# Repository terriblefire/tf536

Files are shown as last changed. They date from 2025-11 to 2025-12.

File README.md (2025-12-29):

# TF536






A Motorola 68030-based hardware accelerator for Amiga 500 and CDTV computers. The TF536 provides a modern 68030 CPU upgrade with SDRAM expansion, IDE interface, and custom CPLD logic for bus arbitration and peripheral management.

**Note**: For Atari ST systems, see the ST536 derivative available from [Exxos](https://www.exxosforum.co.uk/).

## Discord

https://discord.gg/Q5zfusgnmH

## Overview

The TF536 is an open-source hardware accelerator that replaces the original 68000 CPU in Amiga 500 and CDTV systems with a faster 68030 processor. The design uses a Xilinx XC95144XL/XC95288XL CPLD to implement:

- Bus arbitration between 68030 and host system
- SDRAM controller with Amiga autoconfig support
- IDE/ATA interface (Amiga Gayle chipset emulation)
- 68000 peripheral bus timing (6800-style VPA/VMA)
- Clock generation and speed control
- Interrupt handling and bus error generation

## Features

- **68030 CPU**: Significant performance upgrade from stock 68000
- **SDRAM Expansion**: Up to 128MB of fast RAM via SDRAM controller
- **IDE Interface**: Connect IDE hard drives and CF card adapters
- **Amiga Autoconfig**: Automatic memory configuration (Zorro-II compatible)
- **Multi-Platform**: Support for Amiga 500 and CDTV
- **Boot ROM**: Custom 68k assembly boot code with color cycling demo
- **Hardware Revisions**: Evolution from Rev 1 to Rev 2 with improvements
- **Automated Manufacturing**: Complete Gerber, BOM, and CPL generation

## Supported Platforms

The TF536 firmware supports two different target platforms, selected at compile time:

- **A500**: Amiga 500 configuration
- **CDTV**: Commodore CDTV configuration (different ROM decode)

Each platform has specific CPLD defines (`A500`, `CDTV`) that customize the memory map and bus interface behavior.

## Hardware Revisions

### Revision 2 (Current)
The current repository contains the **Rev 2** design (`boards/tf536r2/`), which includes:
- 4-layer PCB design
- Improved signal integrity
- JLCPCB-compatible manufacturing outputs
- Both top and bottom component placement
- Configurable IDE interface (buffered or unbuffered)

### Revision 1
Legacy design available in `boards/tf536r1/` with earlier schematic iterations.

## IDE Interface Build Options

The TF536 supports two mutually exclusive IDE interface configurations:

- **Unbuffered (Default)**: Populate RN5-RN10 with 0Ω resistor networks
- **Buffered**: Populate IC4, IC5, IC6 with buffer ICs

⚠️ **Important**: Do not populate both options simultaneously.

See [IDE_BUILD_OPTIONS.md](IDE_BUILD_OPTIONS.md) for detailed information on choosing and assembling the appropriate configuration.

## Repository Structure

```
tf536/
├── rtl/                    # Verilog RTL source code
│   ├── main_top.v         # Top-level CPLD module (parametric)
│   ├── clocks.v           # Clock generation and CPU speed control
│   ├── sdram.v            # SDRAM controller with burst support
│   ├── sdram_init.v       # SDRAM initialization state machine
│   ├── autoconfig.v       # Amiga Zorro-II autoconfiguration
│   ├── bus.v              # Bus delay and arbitration logic
│   ├── m6800.v            # Motorola 6800 peripheral bus timing
│   ├── ata.v              # IDE/ATA interface controller
│   ├── gayle.v            # Amiga Gayle IDE chipset emulation
│   ├── interrupt.v        # Interrupt level management
│   ├── intreqr.v          # Interrupt request register patching
│   └── bootrom.v          # Boot ROM (auto-generated from assembly)
├── rom/                    # Boot ROM assembly source
│   ├── bootrom.asm        # 68k assembly boot code
│   ├── bin2vrlg           # Binary to Verilog converter (Python 3)
│   └── Makefile           # ROM build automation
├── boards/                 # Board-specific build configurations
│   ├── tf536r1/           # Revision 1 board files
│   ├── tf536r2/           # Revision 2 board files (current)
│   │   ├── tf536r2_main_top.v  # Board-specific wrapper
│   │   ├── tf536r2_main.ucf    # Pin constraints
│   │   └── Makefile            # Build targets (a500, cdtv, atarist)
│   ├── Makefile.cpld      # Common CPLD synthesis rules
│   ├── Makefile.inc       # Docker/Xilinx environment setup
│   └── boards.txt         # List of board configurations
├── testsuite/             # Verilog testbenches
│   ├── bus/               # Bus interface tests
│   ├── interrupt/         # Interrupt handling tests
│   └── Makefile.inc       # Common test environment
├── eagle/                 # Eagle CAD hardware designs
│   ├── tf536.sch          # Schematic (3 sheets)
│   ├── tf536.brd          # PCB layout (4-layer)
│   ├── extract_bom.py     # BOM extraction (JLCPCB format)
│   ├── extract_cpl.py     # Component placement list
│   ├── jlcpcb_4_layer_v9.cam  # Gerber generation CAM job
│   └── Makefile           # Automated manufacturing outputs
└── .github/workflows/     # CI/CD automation
    ├── build-firmware.yml     # CPLD firmware builds
    ├── gerbers.yml            # Gerber file generation
    ├── schematic-pdf.yml      # PDF schematic generation
    └── generate_assembly.yml  # BOM and CPL generation
```

## Building the CPLD Firmware

### Prerequisites

- **Linux**: Xilinx ISE 10.1 installed at `/opt/Xilinx/10.1/`
- **macOS/Windows**: Docker (automatically uses terriblefire78/xilinx:v1 container)
- **68k Assembly**: vasmm68k_mot assembler for boot ROM

The build system automatically handles Docker on non-Linux platforms.

### Build Boot ROM

```bash
cd rom
make
```

Generates `bootrom.v` from `bootrom.asm` with embedded version string.

### Build All Platforms

```bash
cd boards/tf536r2
make
```

This compiles CPLD firmware for both platforms using the XC95288XL CPLD:
- `tf536r2_main_top_A500_XC95288XL_PHASE_7.jed` (Amiga 500)
- `tf536r2_main_top_CDTV_XC95288XL_PHASE_7.jed` (CDTV)

### Build Specific Platform

```bash
cd boards/tf536r2
make a500      # Amiga 500
make cdtv      # Commodore CDTV
```

Output: `.jed` (JEDEC programming files) and `.svf` (Serial Vector Format)

### Build Configuration

Key Makefile variables (used internally by `boards/tf536r2/Makefile`):

```makefile
CHIPSIZE=288        # XC95288XL CPLD
CLOCK_PHASE=7       # Clock phase alignment (0-7)
TARGET=A500         # Platform target (A500, CDTV)
```

### Clean Build Artifacts

```bash
cd boards
make clean       # Remove intermediate files, keep .jed
make distclean   # Remove all generated files including .jed
```

### Create Release Package

```bash
cd boards
make zip
```

Generates: `tf536_YYYY_MM_DD_<git-hash>.zip` containing all board `.jed` files.

## Hardware Manufacturing

### Generate Gerber Files

```bash
cd eagle
make gerbers
```

Output: `tf536_<git>_<date>.zip` containing complete 4-layer PCB fabrication package for JLCPCB.

### Generate PDF Schematic

```bash
cd eagle
make pdf
```

Output: `tf536_<git>_<date>.pdf` - Multi-page PDF schematic (3 sheets)

### Generate Assembly Files

```bash
cd eagle
make assembly
```

Generates:
- `tf536_bom.csv` - Bill of Materials (JLCPCB format)
- `tf536_cpl.csv` - Component Placement List for SMT assembly

### Complete Manufacturing Output

```bash
cd eagle
make all         # Gerber files + ZIP
make bom         # Bill of Materials only
make cpl         # Component Placement List only
make clean       # Remove all generated files
```

## RTL Architecture

### Module Hierarchy

**Top-level:** `main_top.v` (parametric, instantiated by board-specific wrapper)

**Key Modules:**
- **`clocks.v`**: Clock management, CPU speed control, 7MHz/100MHz domain crossing
- **`sdram.v`**: SDRAM controller with burst read/write, refresh, autoconfig decode
- **`sdram_init.v`**: SDRAM initialization (precharge, auto-refresh, mode register)
- **`autoconfig.v`**: Amiga Zorro-II autoconfiguration protocol
- **`bus.v`**: Bus delay state machine and control
- **`m6800.v`**: Motorola 6800 peripheral bus timing (VPA/VMA/E-clock)
- **`ata.v`**: IDE/ATA interface with wait state generation
- **`gayle.v`**: Amiga Gayle chipset emulation (IDE interrupt, status)
- **`interrupt.v`**: IPL interrupt level assertion and acknowledgment
- **`intreqr.v`**: INTREQ/INTENA register patching for IDE interrupts
- **`bootrom.v`**: Boot ROM lookup table (auto-generated from assembly)

### Design Patterns

- **Dual-clock design**: CLK7M (7MHz Amiga bus) and CLK100M (system/SDRAM)
- **Bus punting**: Decides when to drive Amiga bus vs. tri-state (HIGHZ)
- **Platform-specific compilation**: `ifdef` directives for A500/CDTV
- **DSACK protocol**: Variable wait state insertion for fast RAM access
- **Cache support**: CBREQ/CBACK/CIIN signals for 68030 cache control

### Memory Map

**Amiga Configuration:**
- `$00000000-$001FFFFF`: Chip RAM (host)
- `$00200000-$009FFFFF`: Autoconfig space
- `$00A00000-$00BFFFFF`: Reserved (CIA, Custom chips)
- `$00C00000-$00DFFFFF`: Slow RAM (host)
- `$00E00000-$00E7FFFF`: Autoconfig ROM
- `$00F00000-$00F7FFFF`: Cartridge ROM (unless CDTV)
- `$00F80000-$00FFFFFF`: System ROM (Kickstart)
- `$01000000+`: Fast RAM (SDRAM, autoconfigured)

**CDTV Configuration:**
- ROM decode disabled at `$00F00000` (see `main_top.v:268-272`)

## Testing

Run Verilog testbenches:

```bash
cd testsuite/interrupt
make

cd testsuite/bus
make
```

Testbenches use Icarus Verilog (iverilog) and follow naming convention `test_*.v`.

## Programming the CPLD

The `.jed` files can be programmed using:
- JTAG programmer (Xilinx Platform Cable, etc.)
- xc3sprog with FT232H-based programmer
- Xilinx iMPACT software

## CI/CD Automation

GitHub Actions automatically builds:
- **CPLD Firmware**: On changes to `rtl/`, `boards/`, or `rom/`
- **Gerber Files**: On push to develop/main branches
- **PDF Schematics**: On push to develop/main branches
- **Assembly Files**: On changes to Eagle files or extraction scripts

All build artifacts are uploaded and available for download for 90 days. Tagged releases automatically include manufacturing outputs.

## License

This work is licensed under the Creative Commons Attribution-NoDerivatives 4.0 International License.

Copyright (c) 2016-2025 Stephen J. Leary

You are free to:
- **Share** - copy and redistribute the material in any medium or format for any purpose, even commercially

Under the following terms:
- **Attribution** - You must give appropriate credit, provide a link to the license, and indicate if changes were made
- **NoDerivatives** - If you remix, transform, or build upon the material, you may not distribute the modified material

See the [LICENSE](LICENSE) file for the complete license text, or visit:
https://creativecommons.org/licenses/by-nd/4.0/

## Community

Join the TerribleFire Discord for support, discussions, and updates: https://discord.gg/aXGkKWJQ

## Credits

- Hardware design: Stephen Leary
- CPLD development: Stephen Leary
- Open source contributions welcome!

---

**Note**: This is a complex hardware project requiring experience with:
- Eagle CAD for hardware modifications
- Verilog HDL for CPLD changes
- 68000/68030 assembly for boot ROM modifications
- Xilinx ISE 10.1 toolchain for CPLD synthesis
- PCB fabrication and SMT assembly services

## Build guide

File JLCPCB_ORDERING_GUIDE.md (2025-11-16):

# JLCPCB Ordering Guide for the **TF536** Project

This guide walks you step‑by‑step through ordering the **TF536** PCB from JLCPCB using the files provided in the GitHub repository: <https://github.com/terriblefire/tf536>

It is written for beginners and assumes **no prior PCB ordering experience**.

---

## 📁 1. Download and Extract the Release Package

1. Go to the GitHub repository: <https://github.com/terriblefire/tf536>
2. Open the **Releases** section.
3. Download the **single release ZIP file** (e.g., `tf536_v1.0.0.zip`).
4. Extract the ZIP. You will see a structure like this:

```
assembly/
    tf536_bom.csv
    tf536_cpl.csv

pcb/
    tf536_XXXX.zip   (Gerber manufacturing file)

firmware/
    *.jed files (A500 and CDTV variants)

docs/
    PDF documentation, README, LICENSE, IDE_BUILD_OPTIONS.md
```

The files needed for JLCPCB are:
- **Gerber ZIP file:** located in the `pcb/` folder
- **BOM file:** `assembly/tf536_bom.csv`
- **CPL file:** `assembly/tf536_cpl.csv`

---

## 🏭 2. Start a PCB Order on JLCPCB

1. Go to **https://jlcpcb.com**
2. Click **"Order Now"** or **"Quote Now"**.
3. Drag and drop the **Gerber ZIP file** into the upload area.

JLCPCB will automatically detect the board size and number of layers.

> **Note:** JLCPCB does *not* always detect PCB thickness. For TF536, set **1.6 mm thickness manually**.

---

## ⚙️ 3. Configure the PCB Options (Minimal Setup)

The default settings are fine unless otherwise specified by the project.

Recommended settings:

- **Quantity:** 5 or 10 (your choice)
- **PCB Color:** Any (personal preference)
- **Thickness:** 1.6 mm (set manually if not detected)
- **Surface Finish:** HASL or ENIG (ENIG gives nicer gold pads but costs more)
- **Remove Order Number:** Optional (JLCPCB may charge extra)

Everything else can remain at default unless the project documentation says otherwise.

---

## 🤖 4. Add PCB Assembly (If you want components pre‑soldered)

If this project supports assembly (check the repo):

1. Enable **"PCB Assembly"**
2. Select **Left Side / Top Side** (as required by the project)
3. Upload the following when prompted:
   - **BOM file**
   - **CPL file**

JLCPCB will parse the files and show a component placement preview.

### Review the Assembly Bill of Materials

JLCPCB will display:
- A list of recognised components
- Any unmatched parts (you may need to pick substitutes)
- Costs for assembly

> If any parts show as *"Not Found"*, check the BOM or the GitHub project's documentation for substitute part numbers.

---

## 🔍 5. Review the PCB Preview

You will see:
- The Gerber viewer (copper traces, drill holes, etc.)
- Assembly view (if assembly is enabled)

Make sure:
- The board outline looks correct
- Components appear on the correct side
- No warnings are shown

---

## 🛒 6. Add to Cart and Checkout

1. Click **"Add to Cart"**
2. Verify your order summary
3. Proceed to **Checkout**
4. Enter your shipping address
5. Choose a shipping method (DHL is fastest)
6. Pay using:
   - Credit/Debit card
   - PayPal
   - Other supported methods

---

## 📦 7. Wait for Production

Typical manufacturing times:
- **Bare PCBs:** 2–3 days
- **Assembly:** 3–7 days (depends on part availability)

Shipping time varies by region.

You can track the order progress in your JLCPCB account.

---

## 🎉 8. When the Boards Arrive

Inside the package you will find:
- Your PCBs (bare or assembled)
- Any remaining unused components (for assembly orders)
- QC sticker or summary

Inspect the board visually. If assembled, verify correct component placement.

---

## 🧩 9. Additional Notes for TF536 Users

- **IDE Interface Options:** The TF536 has two mutually exclusive build options for the IDE interface:
  - **Unbuffered (Default):** Populate RN5-RN10 with 0Ω resistor networks
  - **Buffered:** Populate IC4, IC5, IC6 with buffer ICs
  - ⚠️ **Never populate both!** See `IDE_BUILD_OPTIONS.md` in the docs folder for details.
- Check the GitHub repo for **firmware**, **build notes**, or **updates**.
- Some components may need to be hand‑soldered depending on your chosen configuration.
- Refer to the project README for configuration or installation instructions.

---

## ❓ Need Help?
If you want a version with screenshots, clearer beginner steps, or additional troubleshooting (e.g., BOM import errors), just ask and I can extend this document further.

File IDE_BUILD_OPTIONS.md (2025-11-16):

# TF536 IDE Interface Build Options

The TF536 board supports two different IDE interface configurations. You must choose ONE of these options during assembly - **do not populate both**.

## Option 1: Unbuffered IDE Interface (Default)

**Components to populate:**
- RN5, RN6, RN7, RN8, RN9, RN10 (0Ω resistor networks)

**Components to leave unpopulated:**
- IC4, IC5, IC6 (buffer ICs)

This is the simpler, lower-cost build option suitable for most applications.

## Option 2: Buffered IDE Interface

**Components to populate:**
- IC4, IC5, IC6 (buffer ICs)

**Components to leave unpopulated:**
- RN5, RN6, RN7, RN8, RN9, RN10 (resistor networks)

The buffered interface provides:
- Better signal integrity for longer IDE cables
- Improved electrical isolation between the TF536 and IDE devices
- Enhanced protection for the CPLD and host system

## Important Notes

⚠️ **WARNING**: Do not populate both the resistor networks (RN5-RN10) and the buffer ICs (IC4-IC6) simultaneously. This will cause signal conflicts and may damage the board.

## Choosing the Right Option

### Use Unbuffered (Default) if:
- Using standard length IDE cables (< 18 inches / 45 cm)
- Cost optimization is important
- Board space or component availability is limited

### Use Buffered if:
- Using longer IDE cables
- Requiring maximum signal integrity
- Operating in electrically noisy environments
- Using multiple IDE devices or CF card adapters with high-speed operation

## Assembly Tips

1. If assembling for the first time, start with the unbuffered option (resistor networks)
2. The resistor networks are typically cheaper and easier to source
3. For JLCPCB assembly, specify which option you want in the assembly notes
4. When hand-soldering, double-check that you're only populating one set of components

## BOM Modifications

When ordering from JLCPCB or generating your BOM:

**For Unbuffered build:**
- Include: RN5, RN6, RN7, RN8, RN9, RN10
- Exclude: IC4, IC5, IC6

**For Buffered build:**
- Include: IC4, IC5, IC6
- Exclude: RN5, RN6, RN7, RN8, RN9, RN10

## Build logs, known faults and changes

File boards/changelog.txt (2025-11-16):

RC3 2021/03/31 Fixed the IDE lockup issue and added unit tests so this doesnt regress.

Serial number changed to 536
Product code 4 

RC2 2020/08/02

Advanced the CIA read timing code. Noticed it was managing to read after the data had disappeared from CIA A in DiagROM.

Fixes: A2000 compatibility.

RC1 2020/08/01

Changed the timing for the 030.
Fixes: Turrican II and Damocles.

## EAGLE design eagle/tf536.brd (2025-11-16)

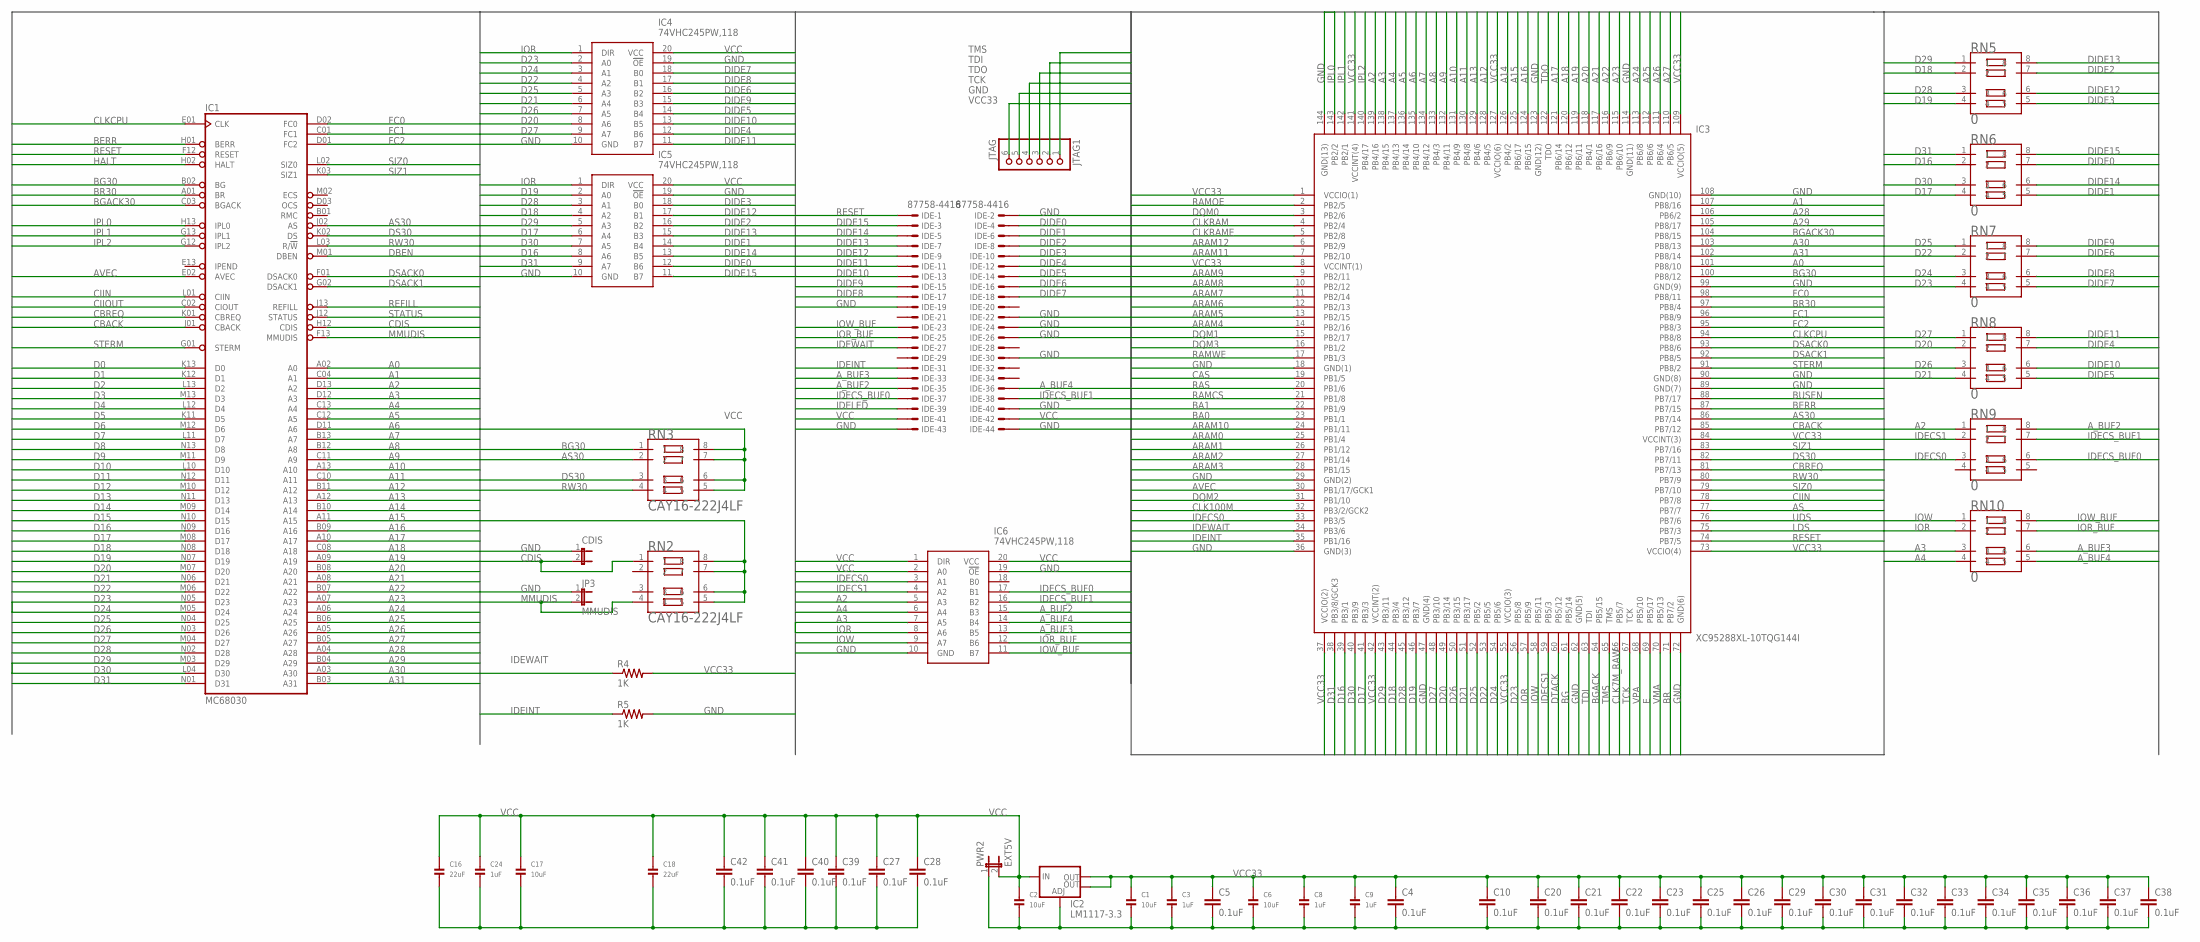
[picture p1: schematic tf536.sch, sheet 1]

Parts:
C1, C2, C6, C17: 10uF; 1206
C3, C8, C9, C24: 1uF; 1206
C4, C5, C10, C20, C21, C22, C23, C25, C26, C27, C28, C29, C30, C31, C32, C33, C34, C35, C36, C37, C38, C39, C40, C41, C42: 0.1uF; 0603-CAP
C16, C18: 22uF; 1206
IC1: MC68030; MPGA128
IC2: LM1117-3.3; SOT223
IC3: XC95288XL-10TQG144I; SAMACSYS_PARTS_QFP50P2200X2200X160-144N
IC4, IC5, IC6: 74VHC245PW,118; SOP65P640X110-20N
IDE: 87758-4416
JP3: MMUDIS; 1X02
JP5: CDIS; 1X02
JTAG1: JTAG; 1X06_ROUND
PWR2: EXT5V; 1X02
R4, R5: 1K; 0603
RN2, RN3: CAY16-222J4LF; RESCAXE80P320X160-8N
RN5, RN6, RN7, RN8, RN9, RN10: 0; RESCAXE80P320X160-8N

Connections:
A0: IC1.A02 (A0), IC3.101 (PB8/10)
A1: IC1.C04 (A1), IC3.107 (PB8/16); also elsewhere on the board
A2: IC1.D13 (A2), IC3.139 (PB4/16), IC6.5 (A3), RN9.1; also elsewhere on the board
A3: IC1.D12 (A3), IC3.138 (PB4/15), IC6.7 (A5), RN10.3; also elsewhere on the board
A4: IC1.C13 (A4), IC3.137 (PB4/13), IC6.6 (A4), RN10.4; also elsewhere on the board
A5: IC1.C12 (A5), IC3.136 (PB4/14); also elsewhere on the board
A6: IC1.D11 (A6), IC3.135 (PB4/10); also elsewhere on the board
A7: IC1.B13 (A7), IC3.134 (PB4/12); also elsewhere on the board
A8: IC1.B12 (A8), IC3.133 (PB4/3); also elsewhere on the board
A9: IC1.C11 (A9), IC3.132 (PB4/11); also elsewhere on the board
A10: IC1.A13 (A10), IC3.131 (PB4/9); also elsewhere on the board
A11: IC1.C10 (A11), IC3.130 (PB4/8); also elsewhere on the board
A12: IC1.B11 (A12), IC3.128 (PB4/5); also elsewhere on the board
A13: IC1.A12 (A13), IC3.129 (PB4/6); also elsewhere on the board
A14: IC1.B10 (A14), IC3.126 (PB4/2); also elsewhere on the board
A15: IC1.A11 (A15), IC3.125 (PB6/17); also elsewhere on the board
A16: IC1.B09 (A16), IC3.124 (PB6/15); also elsewhere on the board
A17: IC1.A10 (A17), IC3.121 (PB6/14); also elsewhere on the board
A18: IC1.C08 (A18), IC3.120 (PB6/12); also elsewhere on the board
A19: IC1.A09 (A19), IC3.119 (PB6/11); also elsewhere on the board
A20: IC1.B08 (A20), IC3.118 (PB4/1); also elsewhere on the board
A21: IC1.A08 (A21), IC3.117 (PB6/16); also elsewhere on the board
A22: IC1.B07 (A22), IC3.116 (PB6/9); also elsewhere on the board
A23: IC1.A07 (A23), IC3.115 (PB6/10); also elsewhere on the board
A24: IC1.A06 (A24), IC3.113 (PB6/8); also elsewhere on the board
A25: IC1.B06 (A25), IC3.112 (PB6/6); also elsewhere on the board
A26: IC1.A05 (A26), IC3.111 (PB6/4); also elsewhere on the board
A27: IC1.B05 (A27), IC3.110 (PB6/5); also elsewhere on the board
A28: IC1.A04 (A28), IC3.106 (PB6/2); also elsewhere on the board
A29: IC1.B04 (A29), IC3.105 (PB8/17); also elsewhere on the board
A30: IC1.A03 (A30), IC3.103 (PB8/13); also elsewhere on the board
A31: IC1.B03 (A31), IC3.102 (PB8/14); also elsewhere on the board
ARAM0: IC3.25 (PB1/4); also elsewhere on the board
ARAM1: IC3.26 (PB1/12); also elsewhere on the board
ARAM2: IC3.27 (PB1/14); also elsewhere on the board
ARAM3: IC3.28 (PB1/15); also elsewhere on the board
ARAM4: IC3.14 (PB2/16); also elsewhere on the board
ARAM5: IC3.13 (PB2/15); also elsewhere on the board
ARAM6: IC3.12 (PB2/13); also elsewhere on the board
ARAM7: IC3.11 (PB2/14); also elsewhere on the board
ARAM8: IC3.10 (PB2/12); also elsewhere on the board
ARAM9: IC3.9 (PB2/11); also elsewhere on the board
ARAM10: IC3.24 (PB1/11); also elsewhere on the board
ARAM11: IC3.7 (PB2/10); also elsewhere on the board
ARAM12: IC3.6 (PB2/9); also elsewhere on the board
AS: IC3.77 (PB7/7); also elsewhere on the board
AS30: IC1.J02 (AS), IC3.86 (PB7/14), RN3.2
AVEC: IC1.E02 (AVEC), IC3.30 (PB1/17/GCK1)
A_BUF2: IC6.15 (B3), IDE.35, RN9.8
A_BUF3: IC6.13 (B5), IDE.33, RN10.6
A_BUF4: IC6.14 (B4), IDE.36, RN10.5
BA0: IC3.23 (PB1/1); also elsewhere on the board
BA1: IC3.22 (PB1/9); also elsewhere on the board
BERR: IC1.H01 (BERR), IC3.87 (PB7/15); also elsewhere on the board
BG: IC3.61 (PB5/14); also elsewhere on the board
BG30: IC1.B02 (BG), IC3.100 (PB8/12), RN3.1
BGACK: IC3.64 (PB5/15); also elsewhere on the board
BGACK30: IC1.C03 (BGACK), IC3.104 (PB8/15)
BR: IC3.71 (PB7/2); also elsewhere on the board
BR30: IC1.A01 (BR), IC3.97 (PB8/4)
BUSEN: IC3.88 (PB7/17); also elsewhere on the board
CAS: IC3.19 (PB1/5); also elsewhere on the board
CBACK: IC1.J01 (CBACK), IC3.85 (PB7/12)
CBREQ: IC1.K01 (CBREQ), IC3.81 (PB7/13)
CDIS: IC1.H12 (CDIS), JP5.2, RN2.1
CIIN: IC1.L01 (CIIN), IC3.78 (PB7/8)
CIIOUT: IC1.C02 (CIOUT)
CLK7M_RAW: IC3.66 (PB5/7); also elsewhere on the board
CLK100M: IC3.32 (PB3/2/GCK2); also elsewhere on the board
CLKCPU: IC1.E01 (CLK), IC3.94 (PB8/8)
CLKRAM: IC3.4 (PB2/4); also elsewhere on the board
CLKRAME: IC3.5 (PB2/8); also elsewhere on the board
D0: IC1.K13 (D0); also elsewhere on the board
D1: IC1.K12 (D1); also elsewhere on the board
D2: IC1.L13 (D2); also elsewhere on the board
D3: IC1.M13 (D3); also elsewhere on the board
D4: IC1.L12 (D4); also elsewhere on the board
D5: IC1.K11 (D5); also elsewhere on the board
D6: IC1.M12 (D6); also elsewhere on the board
D7: IC1.L11 (D7); also elsewhere on the board
D8: IC1.N13 (D8); also elsewhere on the board
D9: IC1.M11 (D9); also elsewhere on the board
D10: IC1.L10 (D10); also elsewhere on the board
D11: IC1.N12 (D11); also elsewhere on the board
D12: IC1.M10 (D12); also elsewhere on the board
D13: IC1.N11 (D13); also elsewhere on the board
D14: IC1.M09 (D14); also elsewhere on the board
D15: IC1.N10 (D15); also elsewhere on the board
D16: IC1.N09 (D16), IC3.39 (PB3/1), IC5.8 (A6), RN6.2; also elsewhere on the board
D17: IC1.M08 (D17), IC3.41 (PB3/3), IC5.6 (A4), RN6.4; also elsewhere on the board
D18: IC1.N08 (D18), IC3.44 (PB3/4), IC5.4 (A2), RN5.2; also elsewhere on the board
D19: IC1.N07 (D19), IC3.46 (PB3/7), IC5.2 (A0), RN5.4; also elsewhere on the board
D20: IC1.M07 (D20), IC3.49 (PB3/14), IC4.8 (A6), RN8.2; also elsewhere on the board
D21: IC1.N06 (D21), IC3.51 (PB3/17), IC4.6 (A4), RN8.4; also elsewhere on the board
D22: IC1.M06 (D22), IC3.53 (PB5/5), IC4.4 (A2), RN7.2; also elsewhere on the board
D23: IC1.N05 (D23), IC3.56 (PB5/8), IC4.2 (A0), RN7.4; also elsewhere on the board
D24: IC1.M05 (D24), IC3.54 (PB5/6), IC4.3 (A1), RN7.3; also elsewhere on the board
D25: IC1.N04 (D25), IC3.52 (PB5/2), IC4.5 (A3), RN7.1; also elsewhere on the board
D26: IC1.N03 (D26), IC3.50 (PB3/15), IC4.7 (A5), RN8.3; also elsewhere on the board
D27: IC1.M04 (D27), IC3.48 (PB3/10), IC4.9 (A7), RN8.1; also elsewhere on the board
D28: IC1.N02 (D28), IC3.45 (PB3/12), IC5.3 (A1), RN5.3; also elsewhere on the board
D29: IC1.M03 (D29), IC3.43 (PB3/11), IC5.5 (A3), RN5.1; also elsewhere on the board
D30: IC1.L04 (D30), IC3.40 (PB3/9), IC5.7 (A5), RN6.3; also elsewhere on the board
D31: IC1.N01 (D31), IC3.38 (PB3/8/GCK3), IC5.9 (A7), RN6.1; also elsewhere on the board
DBEN: IC1.M01 (DBEN)
DIDE0: IC5.12 (B6), IDE.4, RN6.7
DIDE1: IC5.14 (B4), IDE.6, RN6.5
DIDE2: IC5.16 (B2), IDE.8, RN5.7
DIDE3: IC5.18 (B0), IDE.10, RN5.5
DIDE4: IC4.12 (B6), IDE.12, RN8.7
DIDE5: IC4.14 (B4), IDE.14, RN8.5
DIDE6: IC4.16 (B2), IDE.16, RN7.7
DIDE7: IC4.18 (B0), IDE.18, RN7.5
DIDE8: IC4.17 (B1), IDE.17, RN7.6
DIDE9: IC4.15 (B3), IDE.15, RN7.8
DIDE10: IC4.13 (B5), IDE.13, RN8.6
DIDE11: IC4.11 (B7), IDE.11, RN8.8
DIDE12: IC5.17 (B1), IDE.9, RN5.6
DIDE13: IC5.15 (B3), IDE.7, RN5.8
DIDE14: IC5.13 (B5), IDE.5, RN6.6
DIDE15: IC5.11 (B7), IDE.3, RN6.8
DQM0: IC3.3 (PB2/6); also elsewhere on the board
DQM1: IC3.15 (PB2/17); also elsewhere on the board
DQM2: IC3.31 (PB1/10); also elsewhere on the board
DQM3: IC3.16 (PB1/2); also elsewhere on the board
DS30: IC1.K02 (DS), IC3.82 (PB7/11), RN3.3
DSACK0: IC1.F01 (DSACK0), IC3.93 (PB8/6)
DSACK1: IC1.G02 (DSACK1), IC3.92 (PB8/5)
DTACK: IC3.60 (PB5/12); also elsewhere on the board
E: IC3.69 (PB5/17); also elsewhere on the board
FC0: IC1.D02 (FC0), IC3.98 (PB8/11); also elsewhere on the board
FC1: IC1.C01 (FC1), IC3.96 (PB8/9); also elsewhere on the board
FC2: IC1.D01 (FC2), IC3.95 (PB8/3); also elsewhere on the board
GND: C1.2, C2.2, C3.2, C4.2, C5.2, C6.2, C8.2, C9.2, C10.2, C16.2, C17.2, C18.2, C20.2, C21.2, C22.2, C23.2, C24.2, C25.2, C26.2, C27.2, C28.2, C29.2, C30.2, C31.2, C32.2, C33.2, C34.2, C35.2, C36.2, C37.2, C38.2, C39.2, C40.2, C41.2, C42.2, IC1.C05 (GND), IC1.C07 (GND), IC1.C09 (GND), IC1.E03 (GND), IC1.E11 (GND), IC1.F03 (GND), IC1.G03 (GND), IC1.G11 (GND), IC1.J03 (GND), IC1.J11 (GND), IC1.L05 (GND), IC1.L07 (GND), IC1.L08 (GND), IC1.L09 (GND), IC2.1 (ADJ), IC3.18 (GND(1)), IC3.29 (GND(2)), IC3.36 (GND(3)), IC3.47 (GND(4)), IC3.62 (GND(5)), IC3.72 (GND(6)), IC3.89 (GND(7)), IC3.90 (GND(8)), IC3.99 (GND(9)), IC3.108 (GND(10)), IC3.114 (GND(11)), IC3.123 (GND(12)), IC3.144 (GND(13)), IC4.10 (GND), IC4.19 (!OE), IC5.10 (GND), IC5.19 (!OE), IC6.10 (GND), IC6.19 (!OE), IDE.2, IDE.19, IDE.22, IDE.24, IDE.26, IDE.30, IDE.40, IDE.43, IDE.44, JP3.1, JP5.1, JTAG1.5, PWR2.1, R5.2; also elsewhere on the board
HALT: IC1.H02 (HALT); also elsewhere on the board
IDECS0: IC3.33 (PB3/5), IC6.3 (A1), RN9.3
IDECS1: IC3.59 (PB5/3), IC6.4 (A2), RN9.2
IDECS_BUF0: IC6.17 (B1), IDE.37, RN9.6
IDECS_BUF1: IC6.16 (B2), IDE.38, RN9.7
IDEINT: IC3.35 (PB1/16), IDE.31, R5.1
IDELED: IDE.39
IDEWAIT: IC3.34 (PB3/6), IDE.27, R4.1
IOR: IC3.57 (PB5/9), IC4.1 (DIR), IC5.1 (DIR), IC6.8 (A6), RN10.2
IOR_BUF: IC6.12 (B6), IDE.25, RN10.7
IOW: IC3.58 (PB5/11), IC6.9 (A7), RN10.1
IOW_BUF: IC6.11 (B7), IDE.23, RN10.8
IPL0: IC1.H13 (IPL0), IC3.143 (PB2/2); also elsewhere on the board
IPL1: IC1.G13 (IPL1), IC3.142 (PB2/1); also elsewhere on the board
IPL2: IC1.G12 (IPL2), IC3.140 (PB4/17); also elsewhere on the board
LDS: IC3.75 (PB7/3); also elsewhere on the board
MMUDIS: IC1.F13 (MMUDIS), JP3.2, RN2.4
RAMCS: IC3.21 (PB1/8); also elsewhere on the board
RAMOE: IC3.2 (PB2/5); also elsewhere on the board
RAMWE: IC3.17 (PB1/3); also elsewhere on the board
RAS: IC3.20 (PB1/6); also elsewhere on the board
REFILL: IC1.J13 (REFILL)
RESET: IC1.F12 (RESET), IC3.74 (PB7/5), IDE.1; also elsewhere on the board
RW30: IC1.L03 (R/!W), IC3.80 (PB7/9), RN3.4; also elsewhere on the board
SIZ0: IC1.L02 (SIZ0), IC3.79 (PB7/10)
SIZ1: IC1.K03 (SIZ1), IC3.83 (PB7/16)
STATUS: IC1.J12 (STATUS)
STERM: IC1.G01 (STERM), IC3.91 (PB8/2)
TCK: IC3.67 (TCK), JTAG1.4
TDI: IC3.63 (TDI), JTAG1.2
TDO: IC3.122 (TDO), JTAG1.3
TMS: IC3.65 (TMS), JTAG1.1
UDS: IC3.76 (PB7/6); also elsewhere on the board
VCC: C2.1, C16.1, C17.1, C18.1, C24.1, C27.1, C28.1, C39.1, C40.1, C41.1, C42.1, IC1.C06 (VCC), IC1.D04 (VCC), IC1.D10 (VCC), IC1.F02 (VCC), IC1.F11 (VCC), IC1.H03 (VCC), IC1.H11 (VCC), IC1.K04 (VCC), IC1.K10 (VCC), IC1.L06 (VCC), IC2.3 (IN), IC4.20 (VCC), IC5.20 (VCC), IC6.1 (DIR), IC6.2 (A0), IC6.20 (VCC), IDE.41, IDE.42, PWR2.2, RN3.5, RN3.6, RN3.7, RN3.8; also elsewhere on the board
VCC33: C1.1, C3.1, C4.1, C5.1, C6.1, C8.1, C9.1, C10.1, C20.1, C21.1, C22.1, C23.1, C25.1, C26.1, C29.1, C30.1, C31.1, C32.1, C33.1, C34.1, C35.1, C36.1, C37.1, C38.1, IC2.2 (OUT), IC2.4 (OUT), IC3.1 (VCCIO(1)), IC3.8 (VCCINT(1)), IC3.37 (VCCIO(2)), IC3.42 (VCCINT(2)), IC3.55 (VCCIO(3)), IC3.73 (VCCIO(4)), IC3.84 (VCCINT(3)), IC3.109 (VCCIO(5)), IC3.127 (VCCIO(6)), IC3.141 (VCCINT(4)), JTAG1.6, R4.2, RN2.5, RN2.6, RN2.7, RN2.8; also elsewhere on the board
VMA: IC3.70 (PB5/13); also elsewhere on the board
VPA: IC3.68 (PB5/10); also elsewhere on the board

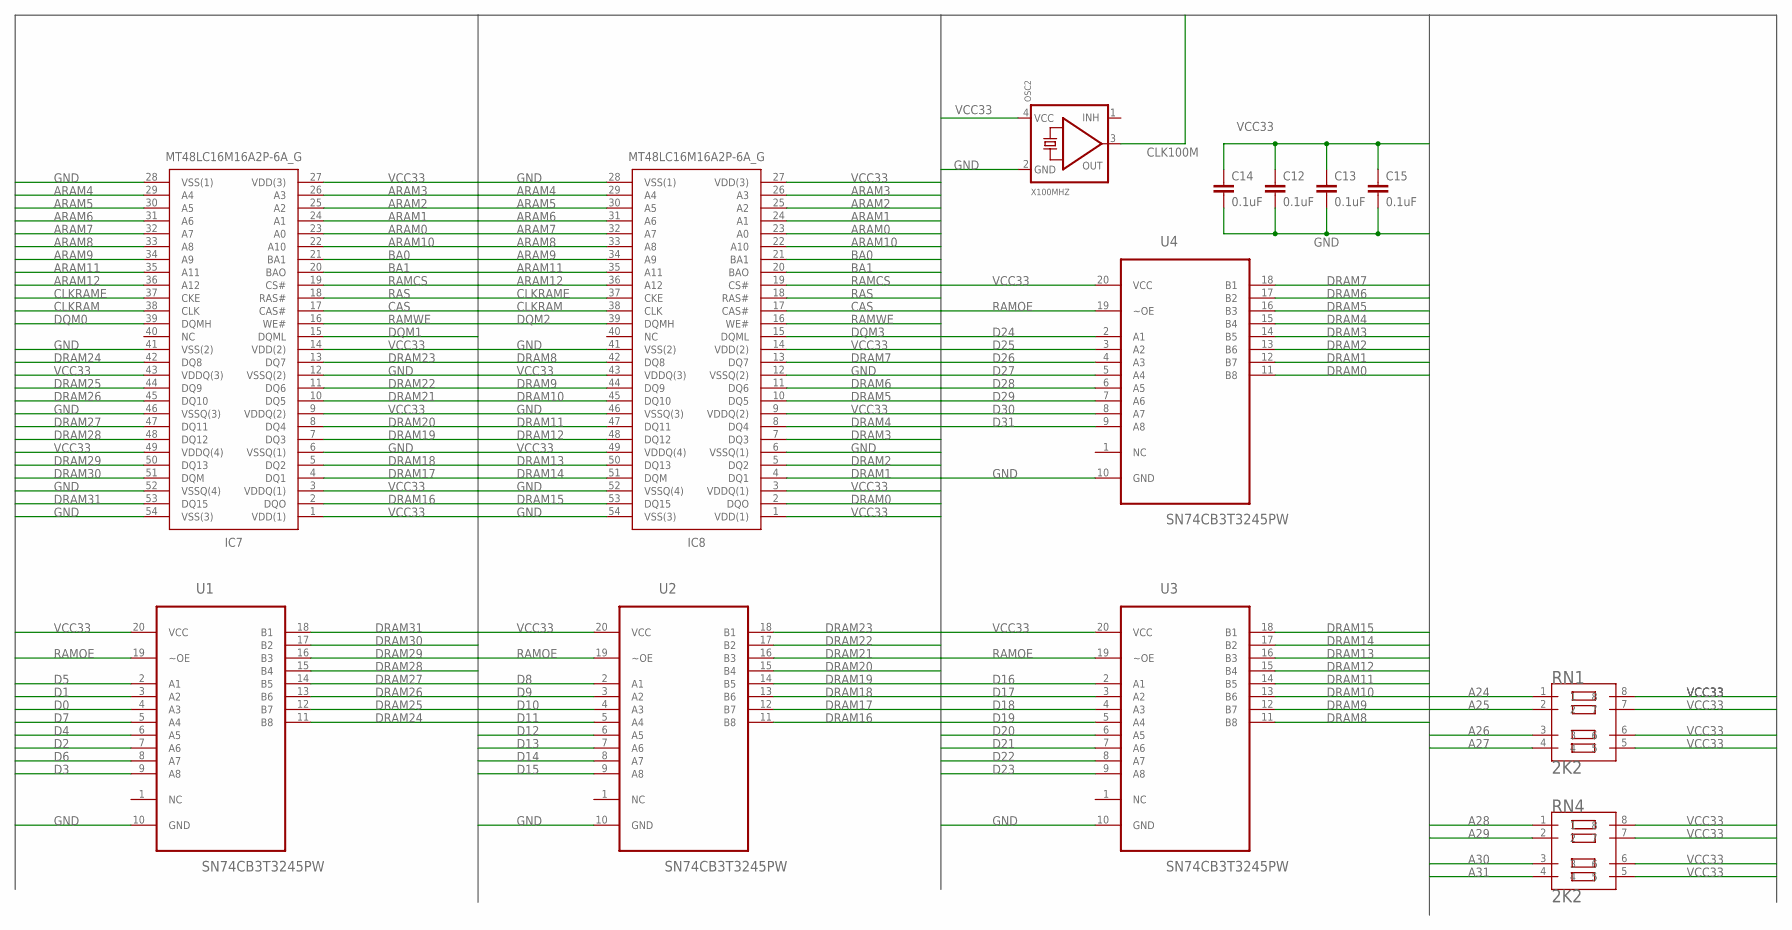
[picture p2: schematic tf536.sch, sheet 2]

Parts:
C12, C13, C14, C15: 0.1uF; 0603-CAP
IC7, IC8: MT48LC16M16A2P-6A_G; SOP80P1176X120-54N
OSC2: X100MHZ; OSC_7X5MM
RN1, RN4: 2K2; RESCAXE80P320X160-8N
U1, U2, U3, U4: SN74CB3T3245PW; SOP65P640X120-20N

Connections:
A24: RN1.1; also elsewhere on the board
A25: RN1.2; also elsewhere on the board
A26: RN1.3; also elsewhere on the board
A27: RN1.4; also elsewhere on the board
A28: RN4.1; also elsewhere on the board
A29: RN4.2; also elsewhere on the board
A30: RN4.3; also elsewhere on the board
A31: RN4.4; also elsewhere on the board
ARAM0: IC7.23 (A0), IC8.23 (A0); also elsewhere on the board
ARAM1: IC7.24 (A1), IC8.24 (A1); also elsewhere on the board
ARAM2: IC7.25 (A2), IC8.25 (A2); also elsewhere on the board
ARAM3: IC7.26 (A3), IC8.26 (A3); also elsewhere on the board
ARAM4: IC7.29 (A4), IC8.29 (A4); also elsewhere on the board
ARAM5: IC7.30 (A5), IC8.30 (A5); also elsewhere on the board
ARAM6: IC7.31 (A6), IC8.31 (A6); also elsewhere on the board
ARAM7: IC7.32 (A7), IC8.32 (A7); also elsewhere on the board
ARAM8: IC7.33 (A8), IC8.33 (A8); also elsewhere on the board
ARAM9: IC7.34 (A9), IC8.34 (A9); also elsewhere on the board
ARAM10: IC7.22 (A10), IC8.22 (A10); also elsewhere on the board
ARAM11: IC7.35 (A11), IC8.35 (A11); also elsewhere on the board
ARAM12: IC7.36 (A12), IC8.36 (A12); also elsewhere on the board
BA0: IC7.21 (BA1), IC8.21 (BA1); also elsewhere on the board
BA1: IC7.20 (BAO), IC8.20 (BAO); also elsewhere on the board
CAS: IC7.17 (CAS#), IC8.17 (CAS#); also elsewhere on the board
CLK100M: OSC2.3 (OUT); also elsewhere on the board
CLKRAM: IC7.38 (CLK), IC8.38 (CLK); also elsewhere on the board
CLKRAME: IC7.37 (CKE), IC8.37 (CKE); also elsewhere on the board
D0: U1.4 (A3); also elsewhere on the board
D1: U1.3 (A2); also elsewhere on the board
D2: U1.7 (A6); also elsewhere on the board
D3: U1.9 (A8); also elsewhere on the board
D4: U1.6 (A5); also elsewhere on the board
D5: U1.2 (A1); also elsewhere on the board
D6: U1.8 (A7); also elsewhere on the board
D7: U1.5 (A4); also elsewhere on the board
D8: U2.2 (A1); also elsewhere on the board
D9: U2.3 (A2); also elsewhere on the board
D10: U2.4 (A3); also elsewhere on the board
D11: U2.5 (A4); also elsewhere on the board
D12: U2.6 (A5); also elsewhere on the board
D13: U2.7 (A6); also elsewhere on the board
D14: U2.8 (A7); also elsewhere on the board
D15: U2.9 (A8); also elsewhere on the board
D16: U3.2 (A1); also elsewhere on the board
D17: U3.3 (A2); also elsewhere on the board
D18: U3.4 (A3); also elsewhere on the board
D19: U3.5 (A4); also elsewhere on the board
D20: U3.6 (A5); also elsewhere on the board
D21: U3.7 (A6); also elsewhere on the board
D22: U3.8 (A7); also elsewhere on the board
D23: U3.9 (A8); also elsewhere on the board
D24: U4.2 (A1); also elsewhere on the board
D25: U4.3 (A2); also elsewhere on the board
D26: U4.4 (A3); also elsewhere on the board
D27: U4.5 (A4); also elsewhere on the board
D28: U4.6 (A5); also elsewhere on the board
D29: U4.7 (A6); also elsewhere on the board
D30: U4.8 (A7); also elsewhere on the board
D31: U4.9 (A8); also elsewhere on the board
DQM0: IC7.39 (DQMH); also elsewhere on the board
DQM1: IC7.15 (DQML); also elsewhere on the board
DQM2: IC8.39 (DQMH); also elsewhere on the board
DQM3: IC8.15 (DQML); also elsewhere on the board
DRAM0: IC8.2 (DQO), U4.11 (B8)
DRAM1: IC8.4 (DQ1), U4.12 (B7)
DRAM2: IC8.5 (DQ2), U4.13 (B6)
DRAM3: IC8.7 (DQ3), U4.14 (B5)
DRAM4: IC8.8 (DQ4), U4.15 (B4)
DRAM5: IC8.10 (DQ5), U4.16 (B3)
DRAM6: IC8.11 (DQ6), U4.17 (B2)
DRAM7: IC8.13 (DQ7), U4.18 (B1)
DRAM8: IC8.42 (DQ8), U3.11 (B8)
DRAM9: IC8.44 (DQ9), U3.12 (B7)
DRAM10: IC8.45 (DQ10), U3.13 (B6)
DRAM11: IC8.47 (DQ11), U3.14 (B5)
DRAM12: IC8.48 (DQ12), U3.15 (B4)
DRAM13: IC8.50 (DQ13), U3.16 (B3)
DRAM14: IC8.51 (DQM), U3.17 (B2)
DRAM15: IC8.53 (DQ15), U3.18 (B1)
DRAM16: IC7.2 (DQO), U2.11 (B8)
DRAM17: IC7.4 (DQ1), U2.12 (B7)
DRAM18: IC7.5 (DQ2), U2.13 (B6)
DRAM19: IC7.7 (DQ3), U2.14 (B5)
DRAM20: IC7.8 (DQ4), U2.15 (B4)
DRAM21: IC7.10 (DQ5), U2.16 (B3)
DRAM22: IC7.11 (DQ6), U2.17 (B2)
DRAM23: IC7.13 (DQ7), U2.18 (B1)
DRAM24: IC7.42 (DQ8), U1.11 (B8)
DRAM25: IC7.44 (DQ9), U1.12 (B7)
DRAM26: IC7.45 (DQ10), U1.13 (B6)
DRAM27: IC7.47 (DQ11), U1.14 (B5)
DRAM28: IC7.48 (DQ12), U1.15 (B4)
DRAM29: IC7.50 (DQ13), U1.16 (B3)
DRAM30: IC7.51 (DQM), U1.17 (B2)
DRAM31: IC7.53 (DQ15), U1.18 (B1)
GND: C12.2, C13.2, C14.2, C15.2, IC7.6 (VSSQ(1)), IC7.12 (VSSQ(2)), IC7.28 (VSS(1)), IC7.41 (VSS(2)), IC7.46 (VSSQ(3)), IC7.52 (VSSQ(4)), IC7.54 (VSS(3)), IC8.6 (VSSQ(1)), IC8.12 (VSSQ(2)), IC8.28 (VSS(1)), IC8.41 (VSS(2)), IC8.46 (VSSQ(3)), IC8.52 (VSSQ(4)), IC8.54 (VSS(3)), OSC2.2 (GND), U1.10 (GND), U2.10 (GND), U3.10 (GND), U4.10 (GND); also elsewhere on the board
RAMCS: IC7.19 (CS#), IC8.19 (CS#); also elsewhere on the board
RAMOE: U1.19 (~OE), U2.19 (~OE), U3.19 (~OE), U4.19 (~OE); also elsewhere on the board
RAMWE: IC7.16 (WE#), IC8.16 (WE#); also elsewhere on the board
RAS: IC7.18 (RAS#), IC8.18 (RAS#); also elsewhere on the board
VCC33: C12.1, C13.1, C14.1, C15.1, IC7.1 (VDD(1)), IC7.3 (VDDQ(1)), IC7.9 (VDDQ(2)), IC7.14 (VDD(2)), IC7.27 (VDD(3)), IC7.43 (VDDQ(3)), IC7.49 (VDDQ(4)), IC8.1 (VDD(1)), IC8.3 (VDDQ(1)), IC8.9 (VDDQ(2)), IC8.14 (VDD(2)), IC8.27 (VDD(3)), IC8.43 (VDDQ(3)), IC8.49 (VDDQ(4)), OSC2.4 (VCC), RN1.5, RN1.6, RN1.7, RN1.8, RN4.5, RN4.6, RN4.7, RN4.8, U1.20 (VCC), U2.20 (VCC), U3.20 (VCC), U4.20 (VCC); also elsewhere on the board

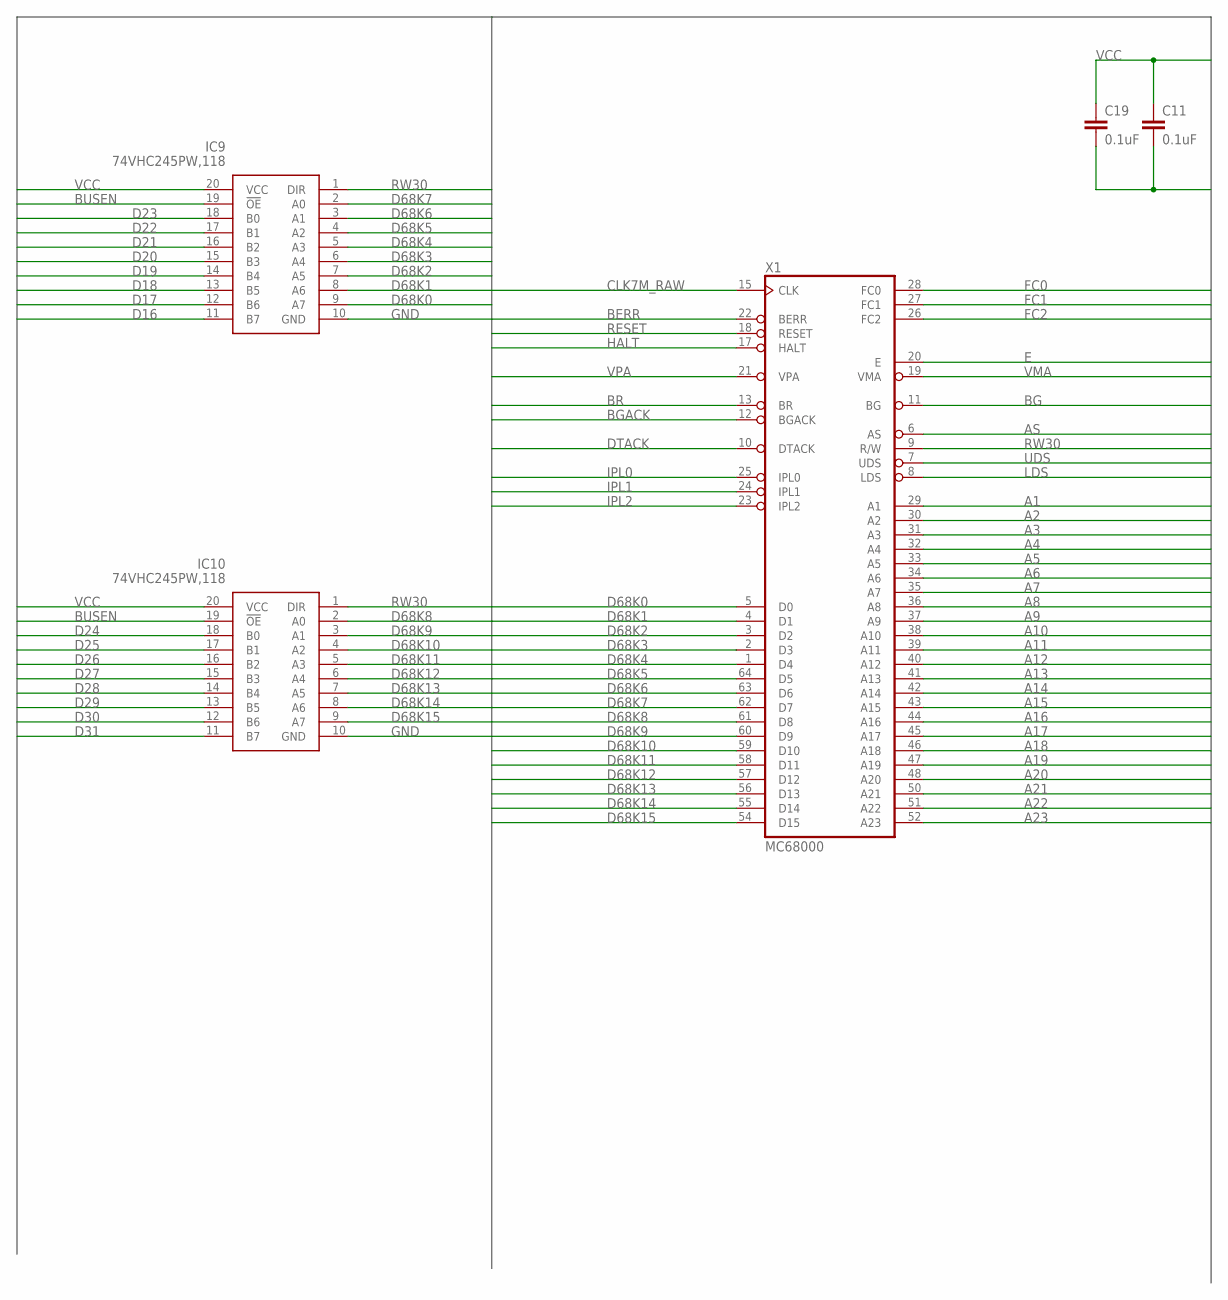
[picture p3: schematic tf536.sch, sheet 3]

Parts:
C11, C19: 0.1uF; 0603-CAP
IC9, IC10: 74VHC245PW,118; SOP65P640X110-20N
X1: MC68000; DIL64

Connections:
A1: X1.29 (A1); also elsewhere on the board
A2: X1.30 (A2); also elsewhere on the board
A3: X1.31 (A3); also elsewhere on the board
A4: X1.32 (A4); also elsewhere on the board
A5: X1.33 (A5); also elsewhere on the board
A6: X1.34 (A6); also elsewhere on the board
A7: X1.35 (A7); also elsewhere on the board
A8: X1.36 (A8); also elsewhere on the board
A9: X1.37 (A9); also elsewhere on the board
A10: X1.38 (A10); also elsewhere on the board
A11: X1.39 (A11); also elsewhere on the board
A12: X1.40 (A12); also elsewhere on the board
A13: X1.41 (A13); also elsewhere on the board
A14: X1.42 (A14); also elsewhere on the board
A15: X1.43 (A15); also elsewhere on the board
A16: X1.44 (A16); also elsewhere on the board
A17: X1.45 (A17); also elsewhere on the board
A18: X1.46 (A18); also elsewhere on the board
A19: X1.47 (A19); also elsewhere on the board
A20: X1.48 (A20); also elsewhere on the board
A21: X1.50 (A21); also elsewhere on the board
A22: X1.51 (A22); also elsewhere on the board
A23: X1.52 (A23); also elsewhere on the board
AS: X1.6 (AS); also elsewhere on the board
BERR: X1.22 (BERR); also elsewhere on the board
BG: X1.11 (BG); also elsewhere on the board
BGACK: X1.12 (BGACK); also elsewhere on the board
BR: X1.13 (BR); also elsewhere on the board
BUSEN: IC9.19 (!OE), IC10.19 (!OE); also elsewhere on the board
CLK7M_RAW: X1.15 (CLK); also elsewhere on the board
D16: IC9.11 (B7); also elsewhere on the board
D17: IC9.12 (B6); also elsewhere on the board
D18: IC9.13 (B5); also elsewhere on the board
D19: IC9.14 (B4); also elsewhere on the board
D20: IC9.15 (B3); also elsewhere on the board
D21: IC9.16 (B2); also elsewhere on the board
D22: IC9.17 (B1); also elsewhere on the board
D23: IC9.18 (B0); also elsewhere on the board
D24: IC10.18 (B0); also elsewhere on the board
D25: IC10.17 (B1); also elsewhere on the board
D26: IC10.16 (B2); also elsewhere on the board
D27: IC10.15 (B3); also elsewhere on the board
D28: IC10.14 (B4); also elsewhere on the board
D29: IC10.13 (B5); also elsewhere on the board
D30: IC10.12 (B6); also elsewhere on the board
D31: IC10.11 (B7); also elsewhere on the board
D68K0: IC9.9 (A7), X1.5 (D0)
D68K1: IC9.8 (A6), X1.4 (D1)
D68K2: IC9.7 (A5), X1.3 (D2)
D68K3: IC9.6 (A4), X1.2 (D3)
D68K4: IC9.5 (A3), X1.1 (D4)
D68K5: IC9.4 (A2), X1.64 (D5)
D68K6: IC9.3 (A1), X1.63 (D6)
D68K7: IC9.2 (A0), X1.62 (D7)
D68K8: IC10.2 (A0), X1.61 (D8)
D68K9: IC10.3 (A1), X1.60 (D9)
D68K10: IC10.4 (A2), X1.59 (D10)
D68K11: IC10.5 (A3), X1.58 (D11)
D68K12: IC10.6 (A4), X1.57 (D12)
D68K13: IC10.7 (A5), X1.56 (D13)
D68K14: IC10.8 (A6), X1.55 (D14)
D68K15: IC10.9 (A7), X1.54 (D15)
DTACK: X1.10 (DTACK); also elsewhere on the board
E: X1.20 (E); also elsewhere on the board
FC0: X1.28 (FC0); also elsewhere on the board
FC1: X1.27 (FC1); also elsewhere on the board
FC2: X1.26 (FC2); also elsewhere on the board
GND: C11.2, C19.2, IC9.10 (GND), IC10.10 (GND), X1.16 (GND), X1.53 (GND); also elsewhere on the board
HALT: X1.17 (HALT); also elsewhere on the board
IPL0: X1.25 (IPL0); also elsewhere on the board
IPL1: X1.24 (IPL1); also elsewhere on the board
IPL2: X1.23 (IPL2); also elsewhere on the board
LDS: X1.8 (LDS); also elsewhere on the board
RESET: X1.18 (RESET); also elsewhere on the board
RW30: IC9.1 (DIR), IC10.1 (DIR), X1.9 (R/W); also elsewhere on the board
UDS: X1.7 (UDS); also elsewhere on the board
VCC: C11.1, C19.1, IC9.20 (VCC), IC10.20 (VCC), X1.14 (VCC), X1.49 (VCC); also elsewhere on the board
VMA: X1.19 (VMA); also elsewhere on the board
VPA: X1.21 (VPA); also elsewhere on the board

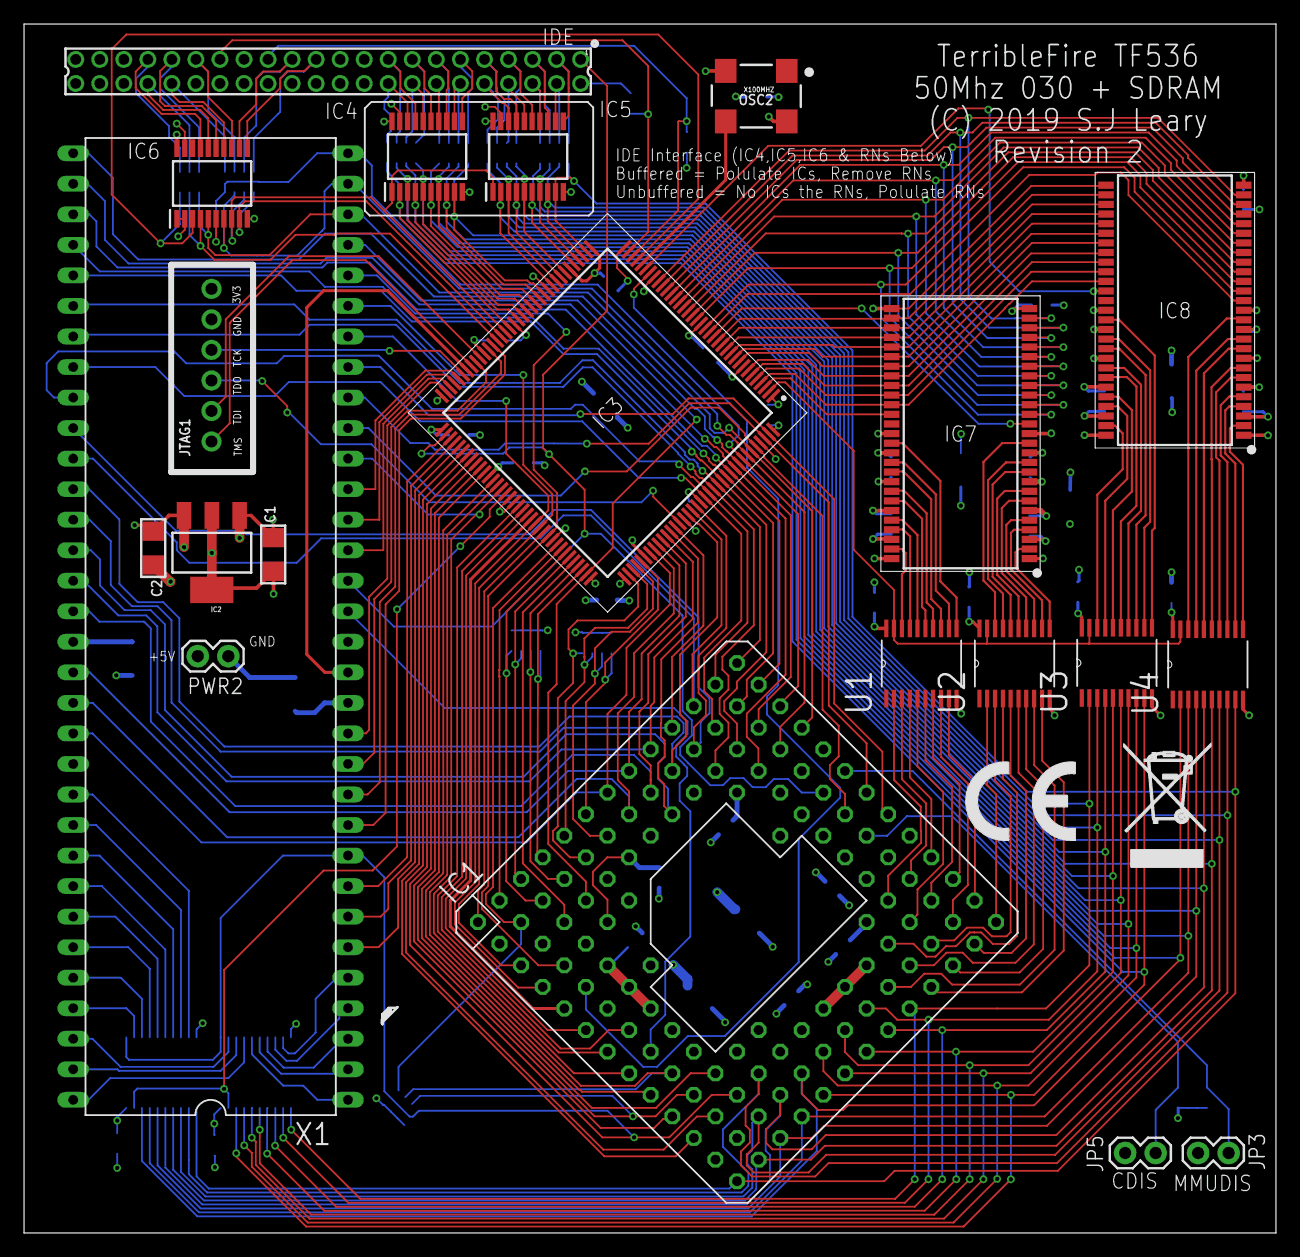
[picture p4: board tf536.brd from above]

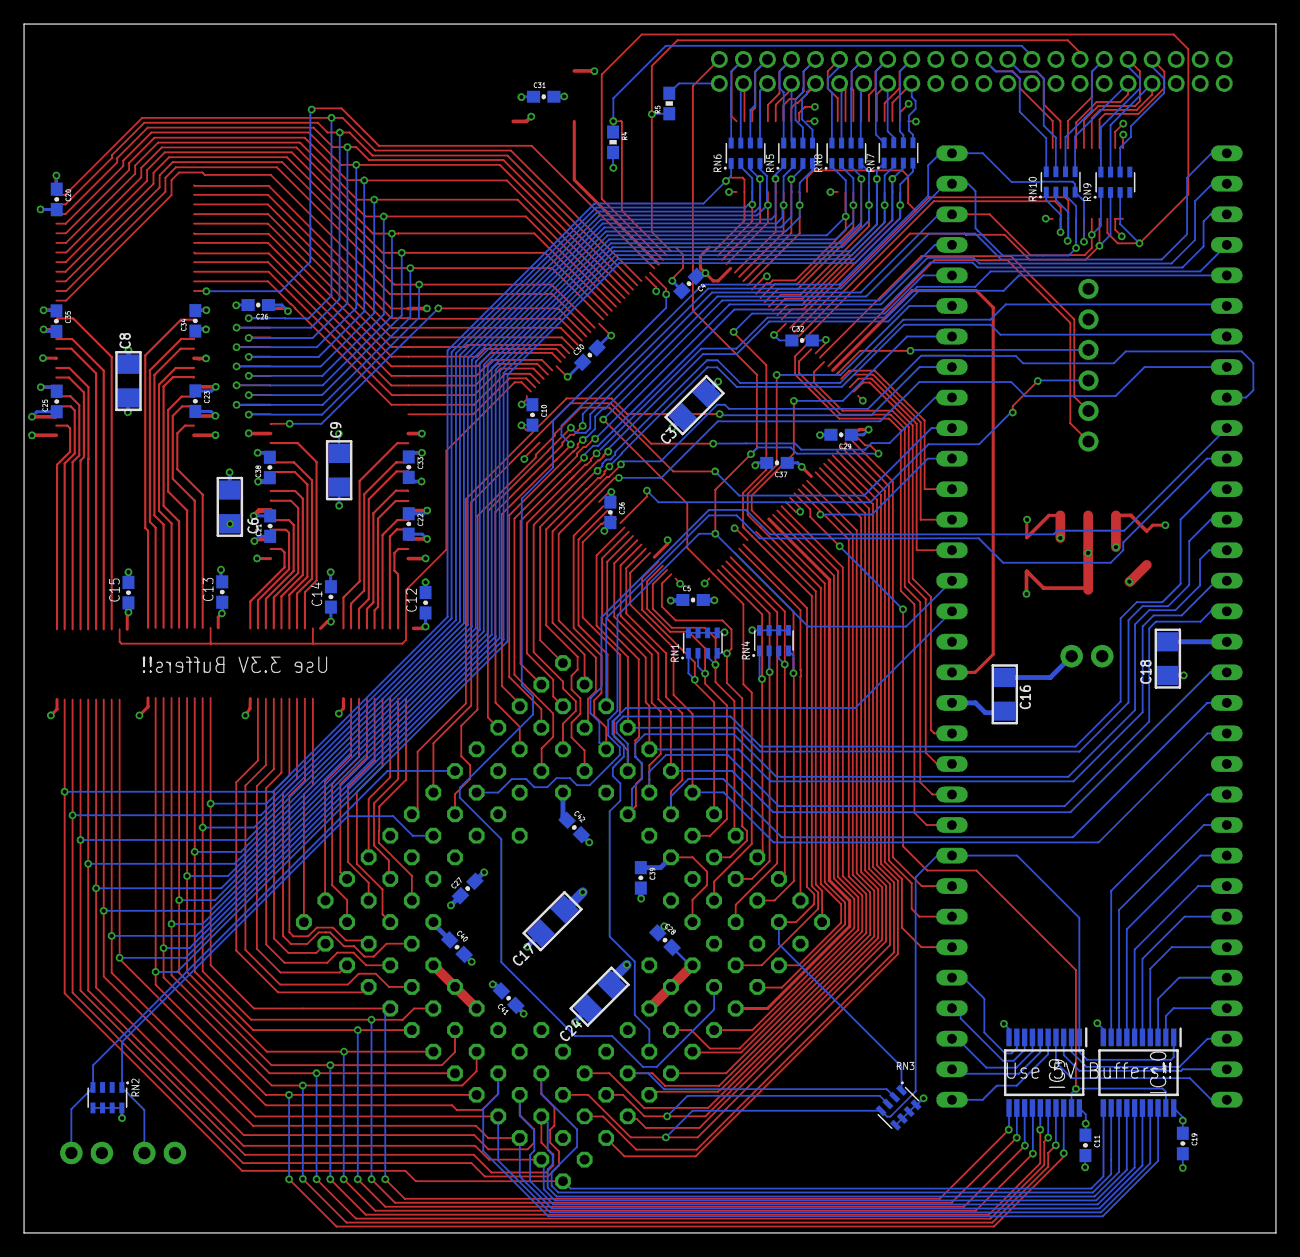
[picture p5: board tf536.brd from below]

Board: 4 copper layers, 104.1 x 100.6 mm, 74 parts (53 on the bottom side), 214 nets.

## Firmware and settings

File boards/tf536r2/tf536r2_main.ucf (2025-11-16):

# Copyright (C) 2016-2017, Stephen J. Leary
# All rights reserved.
#
# This file is part of TF530 (Terrible Fire 030 Accelerator)
#
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
NET "A<0>"      LOC="101";
NET "A<1>"      LOC="107";
NET "A<2>"      LOC="139";
NET "A<3>"      LOC="138";
NET "A<4>"      LOC="137";
NET "A<5>"      LOC="136";
NET "A<6>"      LOC="135";
NET "A<7>"      LOC="134";
NET "A<8>"      LOC="133";
NET "A<9>"      LOC="132";
NET "A<10>"      LOC="131";
NET "A<11>"      LOC="130";
NET "A<12>"      LOC="128";
NET "A<13>"      LOC="129";
NET "A<14>"      LOC="126";
NET "A<15>"      LOC="125";
NET "A<16>"      LOC="124";
NET "A<17>"      LOC="121";
NET "A<18>"      LOC="120";
NET "A<19>"      LOC="119";
NET "A<20>"      LOC="118";
NET "A<21>"      LOC="117";
NET "A<22>"      LOC="116";
NET "A<23>"      LOC="115";
NET "A<24>"      LOC="113";
NET "A<25>"      LOC="112";
NET "A<26>"      LOC="111";
NET "A<27>"      LOC="110";
NET "A<28>"      LOC="106";
NET "A<29>"      LOC="105";
NET "A<30>"      LOC="103";
NET "A<31>"      LOC="102";
NET "ARAM<0>"      LOC="25";
NET "ARAM<1>"      LOC="26";
NET "ARAM<2>"      LOC="27";
NET "ARAM<3>"      LOC="28";
NET "ARAM<4>"      LOC="14";
NET "ARAM<5>"      LOC="13";
NET "ARAM<6>"      LOC="12";
NET "ARAM<7>"      LOC="11";
NET "ARAM<8>"      LOC="10";
NET "ARAM<9>"      LOC="9";
NET "ARAM<10>"      LOC="24";
NET "ARAM<11>"      LOC="7";
NET "ARAM<12>"      LOC="6";
NET "AS"      LOC="77";
NET "AS30"      LOC="86";
NET "AVEC"      LOC="30";
NET "BA<0>"      LOC="23";
NET "BA<1>"      LOC="22";
NET "BERR"      LOC="87";
NET "BG"      LOC="61";
NET "BG30"      LOC="100";
NET "BGACK"      LOC="64";
NET "BGACK30"      LOC="104";
NET "BR"      LOC="71";
NET "BR30"      LOC="97";
NET "BUSEN"      LOC="88";
NET "CAS"      LOC="19";
NET "CBACK"      LOC="85";
NET "CBREQ"      LOC="81";
NET "CIIN"      LOC="78";
NET "CLK7M_RAW"      LOC="66";
NET "CLK100M"      LOC="32";
NET "CLKCPU"      LOC="94";
NET "CLKRAM"      LOC="4";
NET "CLKRAME"      LOC="5";
NET "D<0>"      LOC="39";
NET "D<1>"      LOC="41";
NET "D<2>"      LOC="44";
NET "D<3>"      LOC="46";
NET "D<4>"      LOC="49";
NET "D<5>"      LOC="51";
NET "D<6>"      LOC="53";
NET "D<7>"      LOC="56";
NET "D<8>"      LOC="54";
NET "D<9>"      LOC="52";
NET "D<10>"      LOC="50";
NET "D<11>"      LOC="48";
NET "D<12>"      LOC="45";
NET "D<13>"      LOC="43";
NET "D<14>"      LOC="40";
NET "D<15>"      LOC="38";
NET "DQM<3>"      LOC="16";
NET "DQM<2>"      LOC="31";
NET "DQM<1>"      LOC="15";
NET "DQM<0>"      LOC="3";
NET "DS30"      LOC="82";
NET "DSACK<0>"      LOC="93";
NET "DSACK<1>"      LOC="92";
NET "DTACK"      LOC="60";
NET "E"      LOC="69";
NET "FC<0>"      LOC="98";
NET "FC<1>"      LOC="96";
NET "FC<2>"      LOC="95";
NET "IDECS<0>"      LOC="33";
NET "IDECS<1>"      LOC="59";
NET "IDEINT"      LOC="35";
#NET "IDEWAIT"      LOC="34";
NET "IOR"      LOC="57";
NET "IOW"      LOC="58";
NET "IPL<0>"      LOC="143";
NET "IPL<1>"      LOC="142";
NET "IPL<2>"      LOC="140";
NET "LDS"      LOC="75";
NET "RAMCS"      LOC="21";
NET "RAMOE"      LOC="2";
NET "RAMWE"      LOC="17";
NET "RAS"      LOC="20";
NET "RESET"      LOC="74";
NET "RW30"      LOC="80";
NET "SIZ<0>"      LOC="79";
NET "SIZ<1>"      LOC="83";
NET "STERM"      LOC="91";
NET "UDS"      LOC="76";
NET "VMA"      LOC="70";
NET "VPA"      LOC="68";

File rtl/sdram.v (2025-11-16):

`timescale 1ns / 1ps

/*
TF536 - 68030 Accelerator for Amiga 500/CDTV

Copyright (c) 2016-2025 Stephen J. Leary

This work is licensed under the Creative Commons Attribution-NoDerivatives
4.0 International License. To view a copy of this license, visit
http://creativecommons.org/licenses/by-nd/4.0/ or send a letter to
Creative Commons, PO Box 1866, Mountain View, CA 94042, USA.
*/

module sdram(

           input        RESET,
           input        CLKCPU,
           input        CLK,
           input        ACCESS,

           input [31:0] A,
           input [1:0]  SIZ,

           input        AS30,
           input        RW30,
           input        DS30,

           // cache and burst control
           output       CBACK,
           output       CIIN,
           input        CBREQ,
           output       STERM,
           output       WAIT,

           // ram chip control
           //  SDRAM Control
           output			CLKRAME,
           output [12:0]    ARAM,
           output [1:0] 	BA,
           output			CAS,
           output [3:0] 	DQM,
           output			RAMWE,
           output			RAS,
           output			RAMCS,
           output			RAMOE,
           output [(12*8)-1:0]     COMMANDNAME


       );

`include "sdram_defines.vinc"

wire        ready;

wire        init_clke;
wire [3:0]  init_command;
wire [12:0] init_address;

reg STERM_D;
reg WAITSTATE;

reg [3:0]   command = CMD_NOP;
reg [3:0]   cycle   = 'd0;
reg [1:0]   bank    = 0;
reg [12:0]  address = 0;

wire refresh;

assign COMMANDNAME = cmd_name(ready ? init_command : command);

localparam MODE = { 3'b000, NO_WRITE_BURST, OP_MODE, CAS_LATENCY, ACCESS_TYPE, BURST_LENGTH};

sdram_init #
    (
        .MODE(MODE)
    )
    INIT(

        .CLK    ( CLK           ),
        .CLKE   ( init_clke     ),
        .RESET  ( RESET         ),

        .CMD    ( init_command  ),
        .ARAM   ( init_address  ),
        .READY  ( ready         ),
        .REFRESH( refresh       )

    );

reg refresh_d;
reg refresh_req;

localparam CYCLE_ACCESS = 'b0;
localparam CYCLE_REFRESH = 'b1;

localparam CYCLE_REFRESH_AUTOREFRESH1 = 5'b10011;
localparam CYCLE_REFRESH_AUTOREFRESH2 = 5'b10111;
localparam CYCLE_REFRESH_COMPLETE= 5'b11111;
localparam CYCLE_ACCESS_START = 5'b00001;
localparam CYCLE_ACCESS_RW = 5'b00010;
localparam CYCLE_ACCESS_COMPLETE = 5'b00011;
localparam CYCLE_ACCESS_BW1 = 5'b00100;
localparam CYCLE_ACCESS_BW2 = 5'b00101;

reg BURSTING = 1'b0;
reg [1:0] BCOUNT = 2'b11;

// a read cycle at a tag aligned address.
wire CAN_BURST = ({A[3:2]} != 2'b00) | CBREQ | ACCESS | ~RW30;
wire [1:0] RAMA = BURSTING ? {A[3:2]} : BCOUNT;

wire BURST_ENDING = (BCOUNT == 2'b11) | BURSTING;

reg cycle_type;
reg can_start;

reg WAIT_BLOCK = 1'b1;

always @(posedge CLK or negedge RESET) begin

    if (RESET == 1'b0) begin

        command     <= CMD_NOP;
        address     <= 'd0;
        bank        <= 'd0;
        refresh_req <= 'b1;
        refresh_d   <= 'b0;
        cycle       <= 'd0;
        cycle_type  <= 'd0;

    end else begin

        command <= CMD_NOP;

        if (AS30 == 1'b1) begin

            can_start <= 1'b0;

        end

        // is a refresh required?
        refresh_d <= refresh;
        if ({refresh, refresh_d} == 2'b01) refresh_req <= 1'b0;

        if (cycle == 'd0) begin

            WAIT_BLOCK <= 1'b1;
            BURSTING <= 1'b1;
            BCOUNT <= 'd0;

            if ((ready | can_start) == 1'b0) begin

                address <= { A[23:11] };

                if (refresh_req == 1'b0) begin

                    cycle_type <= CYCLE_REFRESH;
                    cycle[0] <= 'd1;

                end else if ((ACCESS | AS30 | DS30) == 1'b0) begin

                    BURSTING <= CAN_BURST;
                    cycle_type <= CYCLE_ACCESS;
                    can_start <= 1'b1;
                    cycle[0] <= 'd1;

                    address <= { A[23:11] };
                    command <= CMD_ACTIVE;
                    bank <= A[25:24];

                end

            end

        end else begin

            // process the in progress cycle.
            cycle <= cycle + 'd1;

            casez  ({cycle_type, cycle})

                CYCLE_REFRESH_AUTOREFRESH1: begin
                    //command			<= CMD_PRECHARGE;
                    address[10] 	<= 1'b1;      // precharge all banks
                end

                CYCLE_REFRESH_AUTOREFRESH2: begin
                    command			<= CMD_AUTO_REFRESH;
                end

                CYCLE_ACCESS_RW: begin

                    address[8:0] <= { A[10:4], RAMA };
                    address[12:9] <= RW30 ?  4'b0000 : 4'b0010;
                    command <= RW30 ? CMD_READ : CMD_WRITE;
                    WAIT_BLOCK <= 'b0;
                end

                CYCLE_ACCESS_COMPLETE: begin

                    address[8:0] <= { A[10:4], RAMA };
                    address[12:9] <= BURST_ENDING ? 4'b0010 : 4'b0000; // AUTO PRECHARGE ?
                    command <= RW30 ? CMD_READ : CMD_NOP;
                    BCOUNT <= BCOUNT + 'd1;
                    cycle <= BURST_ENDING ? 'd0 : CYCLE_ACCESS_BW1[3:0];

                end

                CYCLE_REFRESH_COMPLETE: begin
                    refresh_req <= 1'b1;
                    cycle <= 'd0;
                end

                CYCLE_ACCESS_BW1: begin
                    WAIT_BLOCK <= 'b1;
                end

                CYCLE_ACCESS_BW2: begin
                    cycle <= CYCLE_ACCESS_RW[3:0];
                end

                default: begin
                    command <= CMD_NOP;
                end

            endcase

        end

    end

end

always @(posedge CLKCPU or posedge AS30) begin

    if (AS30 == 1'b1) begin

        WAITSTATE <= 1'b1;
        STERM_D <= 1'b1;

    end else begin

        WAITSTATE <= ACCESS | DS30 | WAIT_BLOCK;
        STERM_D <= WAIT_BLOCK;

    end
end


// ram control lines
wire RAMCS3n = A[1] | A[0];
wire RAMCS2n = (~SIZ[1] & SIZ[0] & ~A[0]) | A[1];
wire RAMCS1n = (SIZ[1] & ~SIZ[0] & ~A[1] & ~A[0]) | (~SIZ[1] & SIZ[0] & ~A[1]) |(A[1] & A[0]);
wire RAMCS0n = (~SIZ[1] & SIZ[0] & ~A[1] ) | (~SIZ[1] & SIZ[0] & ~A[0] ) | (SIZ[1] & ~A[1] & ~A[0] ) | (SIZ[1] & ~SIZ[0] & ~A[1] );

assign RAMOE = ACCESS;
assign DQM = {4{ACCESS}} | ({ RAMCS3n, RAMCS2n, RAMCS1n , RAMCS0n} & {4{~RW30}});

assign CIIN =  ~ACCESS;
assign CBACK = BURSTING | CBREQ;

assign RAMCS    = 1'b0;
assign RAS      = ready ? init_command[2] : command[2];
assign CAS      = ready ? init_command[1] : command[1];
assign RAMWE    = ready ? init_command[0] : command[0];

assign ARAM     = ready ? init_address : address;
assign BA       = ready ? 2'b00 : bank;
assign CLKRAME  = 1'b1;

assign STERM = STERM_D;

endmodule

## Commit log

2025-11-16 Initial commit - TF536 68030 Accelerator
    Complete TF536 project with:
    - CPLD firmware (Verilog RTL) for Amiga 500 and CDTV
    - 68k assembly boot ROM
    - Eagle CAD hardware design files (4-layer PCB)
    - Automated build system with Docker support
    - GitHub Actions CI/CD workflows
    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
    [tf536.brd, tf536.sch]
2025-11-16 Add release workflow for automated package creation
    - Build CPLD firmware for both A500 and CDTV
    - Generate Gerbers, BOM, CPL, and schematic PDF
    - Create structured release package with firmware, pcb, assembly, and docs
    - Include all documentation (README, LICENSE, IDE options, JLCPCB guide)
    - Automated release creation on version tags
    - Manual trigger via workflow_dispatch
2025-11-16 Remove XC95144XL variant references from README
    The BOM requires XC95288XL, so remove all documentation of the 144 variant to avoid confusion.
2025-11-16 Updating the schematic to say XC95288XL
    [tf536.brd, tf536.sch]
2025-11-16 Add Eagle netlist and UCF generation tools
    - Add generate_netlist.py to export Eagle schematic to netlist format
    - Add generate_ucf.py to generate UCF files from Eagle netlists
    - Filters power (GND, VCC) and JTAG (TCK/TDI/TDO/TMS) signals
    - Handles 68030-specific signals (AS30, BG30, etc.) correctly
    - Optional --remap-dbus flag to map D16-D31 to D<0>-D<15>
    - Update Eagle schematic signal names to match UCF conventions:
    - CLK7M -> CLK7M_RAW
    - DS30ACK0/1 -> DSACK0/1
    - Fix DQM0-3 pin mapping
    [tf536.brd, tf536.sch]

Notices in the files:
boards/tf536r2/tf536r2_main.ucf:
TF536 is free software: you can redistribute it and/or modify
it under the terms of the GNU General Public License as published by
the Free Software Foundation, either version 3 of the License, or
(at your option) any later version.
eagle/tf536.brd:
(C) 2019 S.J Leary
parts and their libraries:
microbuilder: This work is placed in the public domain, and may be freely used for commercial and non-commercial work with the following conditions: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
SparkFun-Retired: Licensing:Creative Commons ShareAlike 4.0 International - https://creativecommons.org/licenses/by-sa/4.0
